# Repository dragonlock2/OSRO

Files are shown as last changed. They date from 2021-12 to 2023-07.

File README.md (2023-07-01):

# OSRO (Open-Source Reflow Oven)

OSRO is an ESP32-C3 powered WiFi-connected reflow oven controller designed for low cost and ease of use. Web UI is built on React JS for those aesthetics.

## Building

1. Build the web UI.
```
cd webui
npm install
npm run build
```
2. Follow the [instructions](https://docs.espressif.com/projects/esp-idf/en/latest/esp32/get-started/) to get ESP-IDF set up. Currently tested with ESP-IDF `v5.0.2`.
3. Setup the build for the firmware. Make sure to set the WiFi SSID and password under `OSRO WiFi configuration`.
```
cd firmware
get_idf
idf.py set-target esp32c3
idf.py menuconfig
```
4. Build and flash the firmware.
```
cd firmware
idf.py build
idf.py -p <serial port> flash
```

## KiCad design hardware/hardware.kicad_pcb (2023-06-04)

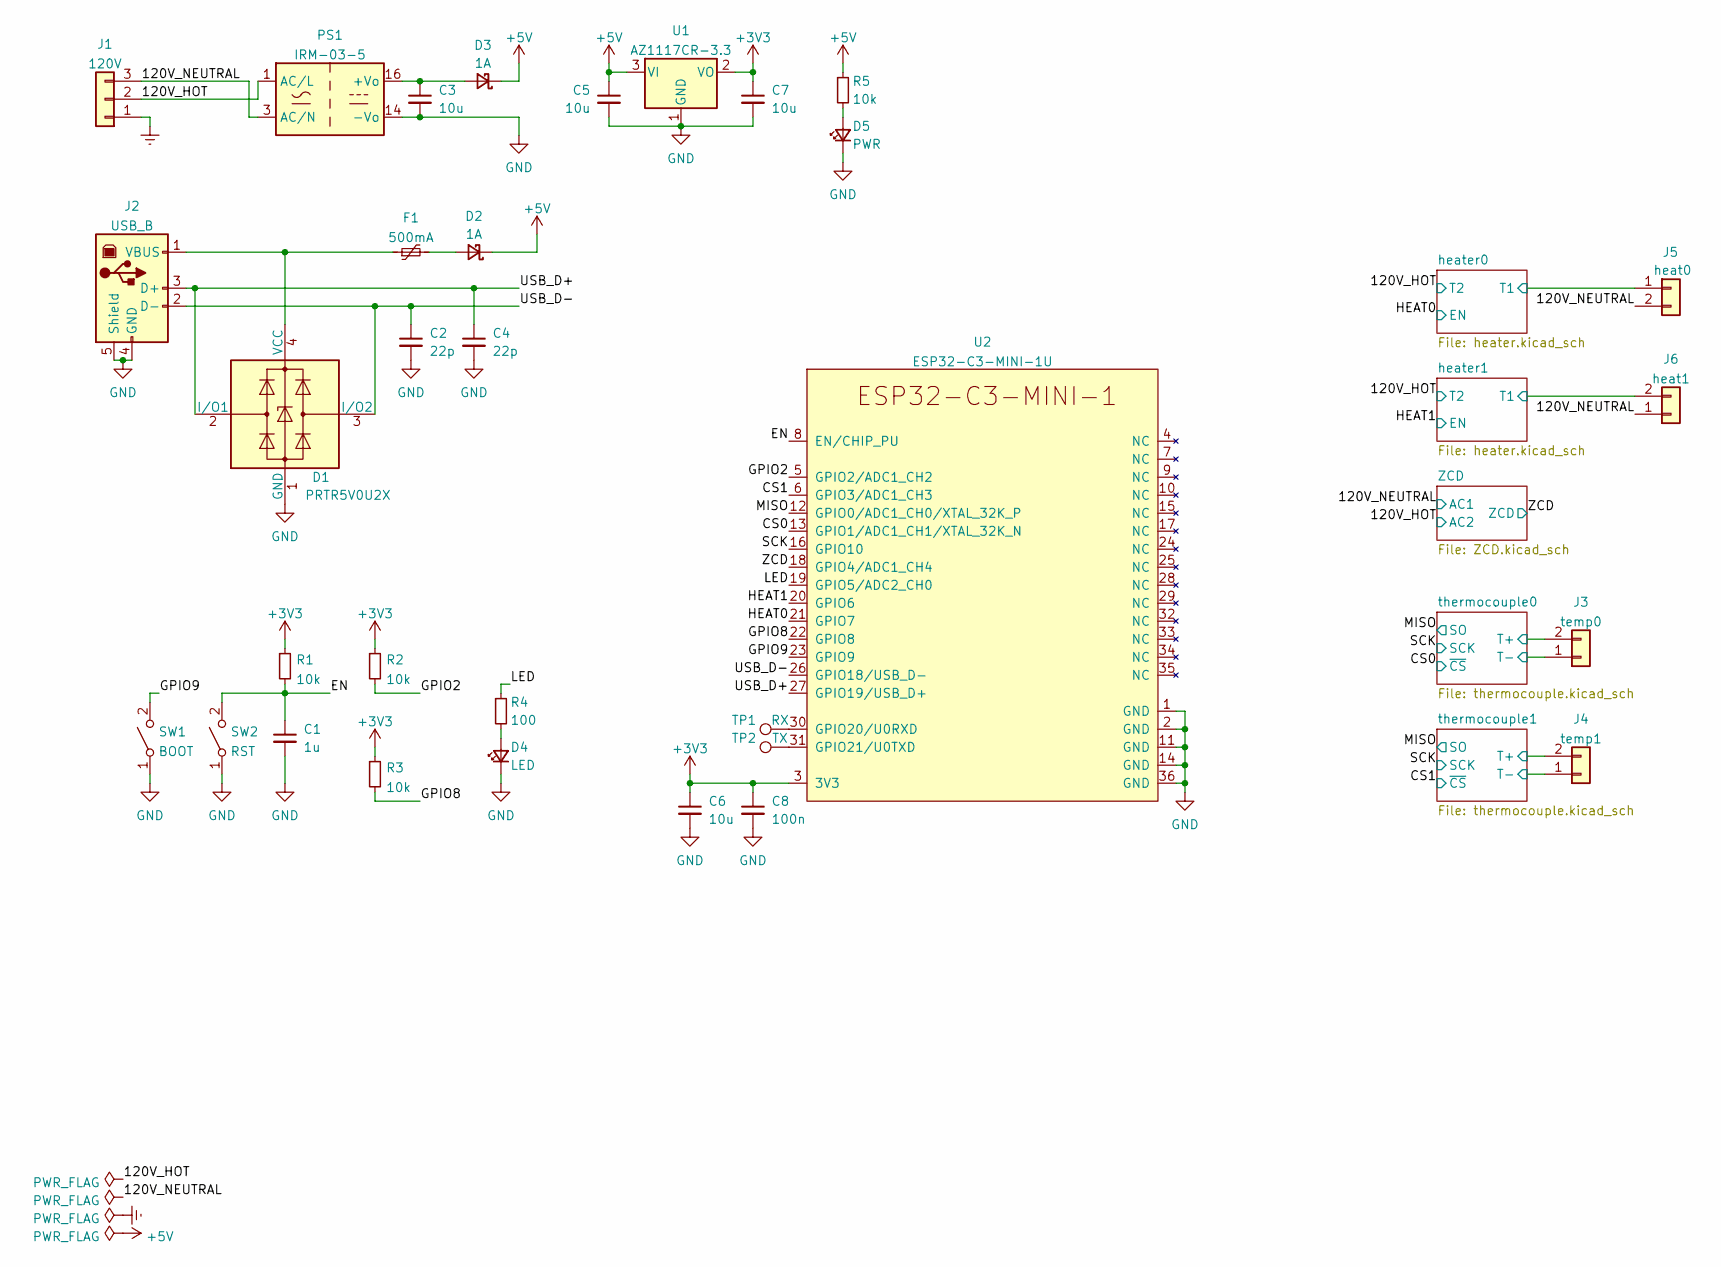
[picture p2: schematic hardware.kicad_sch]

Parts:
C1: 1u; C_0603_1608Metric
C2, C4: 22p; C_0603_1608Metric
C3, C5, C6, C7: 10u; C_0805_2012Metric
C8: 100n; C_0603_1608Metric
D1: PRTR5V0U2X; SOT-143
D2, D3: 1A; D_SOD-123F
D4: LED; LED_0603_1608Metric
D5: PWR; LED_0603_1608Metric
F1: 500mA; Fuse_1206_3216Metric
J1: 120V; Molex_MicroFit+_RH_1row_3pin
J2: USB_B; USB_B_TE_5787834_Vertical
J3: temp0; Molex_DuraClik_RH_2pin
J4: temp1; Molex_DuraClik_RH_2pin
J5: heat0; Molex_MicroFit+_RH_1row_2pin
J6: heat1; Molex_MicroFit+_RH_1row_2pin
PS1: IRM-03-5; Converter_ACDC_MeanWell_IRM-03-xx_THT
R1, R2, R3, R5: 10k; R_0603_1608Metric
R4: 100; R_0603_1608Metric
SW1: BOOT; SW_SPST_PTS810
SW2: RST; SW_SPST_PTS810
TP1: RX; TestPoint_Pad_D2.0mm
TP2: TX; TestPoint_Pad_D2.0mm
U1: AZ1117CR-3.3; SOT-89-3
U2: ESP32-C3-MINI-1U

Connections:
+3V3: C6.1, C7.1, C8.1, R1.1, R2.1, R3.1, U1.2 (VO), U2.3 (3V3); also elsewhere on the board
+5V: C5.1, D2.1 (K), D3.1 (K), R5.1, U1.3 (VI)
/120V_HOT: J1.2, PS1.1 (AC/L); also elsewhere on the board
/120V_NEUTRAL: J1.3, J5.2, J6.1, PS1.3 (AC/N); also elsewhere on the board
/CS0: U2.13 (GPIO1/ADC1_CH1/XTAL_32K_N); also elsewhere on the board
/CS1: U2.6 (GPIO3/ADC1_CH3); also elsewhere on the board
/EN: C1.1, R1.2, SW2.2 (B), U2.8 (EN/CHIP_PU)
/GPIO2: R2.2, U2.5 (GPIO2/ADC1_CH2)
/GPIO8: R3.2, U2.22 (GPIO8)
/GPIO9: SW1.2 (B), U2.23 (GPIO9)
/HEAT0: U2.21 (GPIO7); also elsewhere on the board
/HEAT1: U2.20 (GPIO6); also elsewhere on the board
/LED: R4.1, U2.19 (GPIO5/ADC2_CH0)
/MISO: U2.12 (GPIO0/ADC1_CH0/XTAL_32K_P); also elsewhere on the board
/SCK: U2.16 (GPIO10); also elsewhere on the board
/USB_D+: C4.1, D1.2 (I/O1), J2.3 (D+), U2.27 (GPIO19/USB_D+)
/USB_D-: C2.1, D1.3 (I/O2), J2.2 (D-), U2.26 (GPIO18/USB_D-)
/ZCD: U2.18 (GPIO4/ADC1_CH4); also elsewhere on the board
/heater0/T1: J5.1; also elsewhere on the board
/heater1/T1: J6.2; also elsewhere on the board
/thermocouple0/T+: J3.2; also elsewhere on the board
/thermocouple0/T-: J3.1; also elsewhere on the board
/thermocouple1/T+: J4.2; also elsewhere on the board
/thermocouple1/T-: J4.1; also elsewhere on the board
Earth: J1.1
GND: C1.2, C2.2, C3.2, C4.2, C5.2, C6.2, C7.2, C8.2, D1.1 (GND), D4.1 (K), D5.1 (K), J2.4 (GND), J2.5 (Shield), PS1.14 (-Vo), SW1.1 (A), SW2.1 (A), U1.1 (GND), U2.1 (GND), U2.2 (GND), U2.11 (GND), U2.14 (GND), U2.36 (GND); also elsewhere on the board
unnamed: C3.1, D3.2 (A), PS1.16 (+Vo)
unnamed: D1.4 (VCC), F1.1, J2.1 (VBUS)
unnamed: D2.2 (A), F1.2
unnamed: D4.2 (A), R4.2
unnamed: D5.2 (A), R5.2
unnamed: TP1.1, U2.30 (GPIO20/U0RXD)
unnamed: TP2.1, U2.31 (GPIO21/U0TXD)

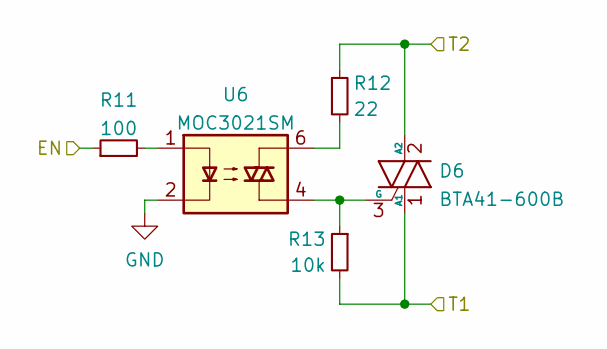
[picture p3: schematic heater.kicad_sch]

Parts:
D6: BTA41-600B; TO-3P-3_Horizontal_TabDown
R11: 100; R_0603_1608Metric
R12: 22; R_0603_1608Metric
R13: 10k; R_0603_1608Metric
U6: MOC3021SM; SMDIP-6_W9.53mm_Clearance8mm

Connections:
/120V_HOT: D6.2 (A2), R12.1; also elsewhere on the board
/HEAT0: R11.1; also elsewhere on the board
/heater0/T1: D6.1 (A1), R13.2; also elsewhere on the board
GND: U6.2; also elsewhere on the board
unnamed: D6.3 (G), R13.1, U6.4
unnamed: R11.2, U6.1
unnamed: R12.2, U6.6

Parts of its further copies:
D7: BTA41-600B; TO-3P-3_Horizontal_TabDown
R14: 100; R_0603_1608Metric
R15: 22; R_0603_1608Metric
R16: 10k; R_0603_1608Metric
U7: MOC3021SM; SMDIP-6_W9.53mm_Clearance8mm

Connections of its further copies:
/120V_HOT: D7.2 (A2), R15.1; also elsewhere on the board
/HEAT1: R14.1; also elsewhere on the board
/heater1/T1: D7.1 (A1), R16.2; also elsewhere on the board
GND: U7.2; also elsewhere on the board
unnamed: D7.3 (G), R16.1, U7.4
unnamed: R14.2, U7.1
unnamed: R15.2, U7.6

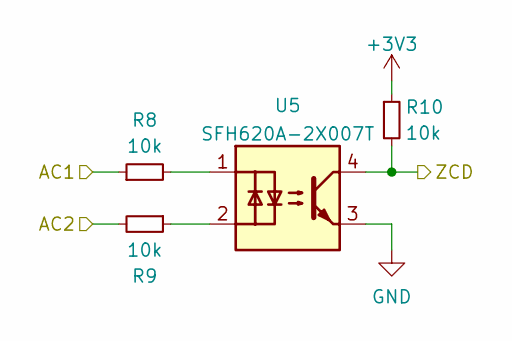
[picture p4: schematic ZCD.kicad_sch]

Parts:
R8, R9: 10k; R_1206_3216Metric
R10: 10k; R_0603_1608Metric
U5: SFH620A-2X007T; SMDIP-4_W9.53mm_Clearance8mm

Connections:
+3V3: R10.1; also elsewhere on the board
/120V_HOT: R9.2; also elsewhere on the board
/120V_NEUTRAL: R8.1; also elsewhere on the board
/ZCD: R10.2, U5.4; also elsewhere on the board
GND: U5.3; also elsewhere on the board
unnamed: R8.2, U5.1
unnamed: R9.1, U5.2

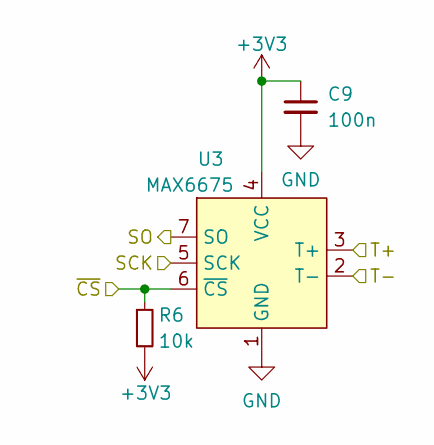
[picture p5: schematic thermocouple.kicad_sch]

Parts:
C9: 100n; C_0603_1608Metric
R6: 10k; R_0603_1608Metric
U3: MAX6675; SO-8_3.9x4.9mm_P1.27mm

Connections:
+3V3: C9.1, R6.2, U3.4 (VCC); also elsewhere on the board
/CS0: R6.1, U3.6 (~CS); also elsewhere on the board
/MISO: U3.7 (SO); also elsewhere on the board
/SCK: U3.5 (SCK); also elsewhere on the board
/thermocouple0/T+: U3.3 (T+); also elsewhere on the board
/thermocouple0/T-: U3.2 (T-); also elsewhere on the board
GND: C9.2, U3.1 (GND); also elsewhere on the board

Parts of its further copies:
C10: 100n; C_0603_1608Metric
R7: 10k; R_0603_1608Metric
U4: MAX6675; SO-8_3.9x4.9mm_P1.27mm

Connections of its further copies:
+3V3: C10.1, R7.2, U4.4 (VCC); also elsewhere on the board
/CS1: R7.1, U4.6 (~CS); also elsewhere on the board
/MISO: U4.7 (SO); also elsewhere on the board
/SCK: U4.5 (SCK); also elsewhere on the board
/thermocouple1/T+: U4.3 (T+); also elsewhere on the board
/thermocouple1/T-: U4.2 (T-); also elsewhere on the board
GND: C10.2, U4.1 (GND); also elsewhere on the board

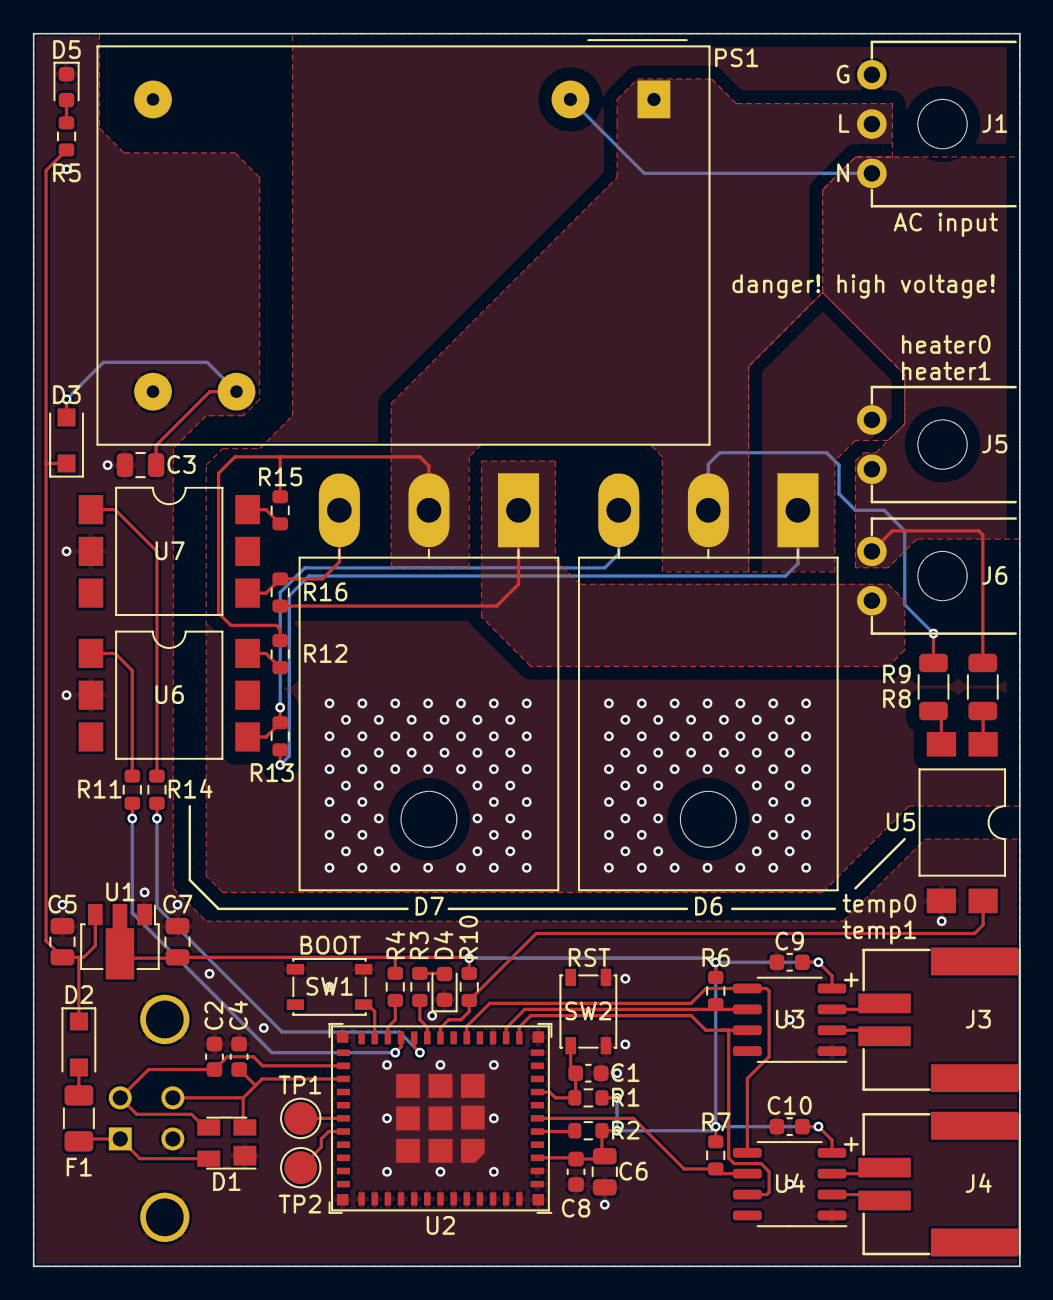
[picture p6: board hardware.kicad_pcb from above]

Board: 2 copper layers, 60.0 x 75.0 mm, 52 parts (1 on the bottom side), 40 nets.

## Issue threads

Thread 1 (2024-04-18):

230V ready?

nikwest, 2024-04-18:
Love the design. From what I can tell it should also work with 230V AC?

dragonlock2, 2024-04-18:
I haven't taken a look at this design in a while, but on a quick analysis it should work. Worst case some of the resistors in the switching circuit need to be resized.

nikwest, 2024-04-19:
ok, thank you. I'll give it a try and let you know, if it works. Any particular resistor you have in mind? I was looking at R12, but as far as I understood it, this is suppose to limit the current and the value is depending on the voltage drop of the triac. So here the AC voltage doesn't really matter.

nikwest, 2024-04-19:
Good point. Didn't think about that.

nikwest, 2024-04-21:
I can't really get resistors with correct ratings. Especially the 10k R13 and R16 I can't get with 400V rating.  I'll need to split it up into 2 5k 200V 803 resistors. Also I think it's better to use 33k for R8/R9 and SFH6206-3 instead of SFH620A-2, which has a slightly better CTR rating.
Therefore I have to touch the PCB layout. The extraparts and esspressif footprint folders are empty in the repository. I guess you haven't committed them due to copyright restrictions?

dragonlock2, 2024-04-21:
Good point on the resistor voltage rating, high voltage ones are harder to find. SFH6206-3 should be fine, parts I choose are what was cheapest on DigiKey at the time or what I had on hand so there's room for optimization.

`extraparts` and `espressif` are submodules, either do a `git clone --recursive` when cloning or a `git submodule init && git submodule update` after cloning to check those out.

nikwest, 2024-06-08:
I made a couple of changes to your design and adapted it for 230V. The first build looks like it works nicely, except that my oven is not strong enough and can't follow the profile temperature so quickly.
Question is, if you want a PR for this to incorporate in your repository or rather keep this version separate?
I also changed from USB-B to a USB-C connector and for my second board I like to use the MAX31855 instead of MAX6675. They are pin compatible, but firmware needs to be adapted.
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

dragonlock2, 2024-06-22:
That looks great! Glad that it's working. I'm a bit lazy to figure the best way to organize two board variants so let's keep your changes in a fork for now. If there's more community interest I'll take a closer look

nikwest, 2024-07-01:
Yes, I agree, just wanted to check back with you. Then I'll keep the fork.

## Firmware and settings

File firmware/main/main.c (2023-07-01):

#include <freertos/FreeRTOS.h>
#include <esp_console.h>
#include <esp_event.h>
#include <esp_log.h>
#include <nvs_flash.h>
#include "wifi.h"
#include "server.h"
#include "oven.h"

static const char *TAG = "main";

void app_main(void) {
    // console init
    esp_console_repl_t *repl = NULL;
    esp_console_repl_config_t repl_config = ESP_CONSOLE_REPL_CONFIG_DEFAULT();
    esp_console_dev_usb_serial_jtag_config_t usbjtag_config = ESP_CONSOLE_DEV_USB_SERIAL_JTAG_CONFIG_DEFAULT();
    esp_console_new_repl_usb_serial_jtag(&usbjtag_config, &repl_config, &repl);
    esp_console_start_repl(repl);

    // other init
    nvs_flash_init();
    esp_event_loop_create_default();
    
    // app init
    oven_init();
    wifi_init();
    server_init();
    ESP_LOGI(TAG, "booted!");
}

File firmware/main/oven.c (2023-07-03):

#include <math.h>
#include <stddef.h>
#include <argtable3/argtable3.h>
#include <freertos/FreeRTOS.h>
#include <freertos/semphr.h>
#include <freertos/task.h>
#include <driver/gpio.h>
#include <driver/spi_master.h>
#include <esp_console.h>
#include <esp_log.h>
#include "oven.h"

/* private data */
#define COUNT_OF(x) (sizeof(x) / sizeof(x[0]))
#define LIMIT(x, low, high) ((x < low) ? (low) : ((x > high) ? (high) : (x)))

static const int MISO_PIN  = 0;
static const int SCK_PIN   = 10;
static const int CS_PINS[] = {3}; // {1, 3};

static const int ZCD_PIN     = 4;
static const int HEAT_PINS[] = {6, 7};

#define PWM_PERIOD (30) // ~0.25s @ 60Hz AC

#define CONTROL_PERIOD (0.25) // s

static const char *TAG = "oven";

static struct {
    SemaphoreHandle_t lock;
    TickType_t        start;
    profile_type_t    type;
    oven_status_t     status;

    struct {
        struct arg_str *kp;
        struct arg_str *ki;
        struct arg_str *kd;
        struct arg_end *end;
    } pid_set_args;
    double kp, ki, kd;
    double int_err, prev_err;

    spi_device_handle_t temps[COUNT_OF(CS_PINS)];

    int pwm_counter;
    int pwm_compare;
    int pwm_compare_next;
} oven_data;

/* private helpers */
static void temp_init(void) {
    const spi_bus_config_t bus_cfg = {
        .mosi_io_num     = -1,
        .miso_io_num     = MISO_PIN,
        .sclk_io_num     = SCK_PIN,
        .max_transfer_sz = 32,
        .flags           = SPICOMMON_BUSFLAG_MASTER,
    };
    spi_bus_initialize(SPI2_HOST, &bus_cfg, SPI_DMA_DISABLED);

    for (int i = 0; i < COUNT_OF(CS_PINS); i++) {
        const spi_device_interface_config_t dev_cfg = {
            .mode           = 1,
            .clock_speed_hz = 4000000, // 4.3 MHz max
            .spics_io_num   = CS_PINS[i],
            .flags          = 0,
            .queue_size     = 1,
        };
        spi_bus_add_device(SPI2_HOST, &dev_cfg, &oven_data.temps[i]);
    }
}

static double temp_get(void) {
    // MAX6675 device
    uint8_t buf[2];
    spi_transaction_t tran = {
        .flags     = 0,
        .length    = sizeof(buf) * 8,
        .tx_buffer = NULL,
        .rx_buffer = buf,
    };

    double sum = 0.0;
    for (int i = 0; i < COUNT_OF(CS_PINS); i++) {
        spi_device_transmit(oven_data.temps[i], &tran);
        uint16_t raw = (buf[0] << 8) | buf[1];
        sum += (raw >> 3) * 0.25;
    }
    return sum / COUNT_OF(CS_PINS); // average all sensors for now
}

static void IRAM_ATTR pwm_handler(void* arg) {
    oven_data.pwm_counter++;
    if (oven_data.pwm_counter >= PWM_PERIOD) {
        oven_data.pwm_counter = 0;
        oven_data.pwm_compare = oven_data.pwm_compare_next;
    }

    bool on = oven_data.pwm_counter < oven_data.pwm_compare;
    for (int i = 0; i < COUNT_OF(HEAT_PINS); i++) {
        gpio_set_level(HEAT_PINS[i], on);
    }
}

static void pwm_init(void) {
    oven_data.pwm_counter      = 0;
    oven_data.pwm_compare      = 0;
    oven_data.pwm_compare_next = 0;

    gpio_reset_pin(ZCD_PIN);
    gpio_set_direction(ZCD_PIN, GPIO_MODE_INPUT);
    gpio_set_pull_mode(ZCD_PIN, GPIO_PULLUP_ONLY);
    gpio_set_intr_type(ZCD_PIN, GPIO_INTR_NEGEDGE);
    gpio_install_isr_service(0);
    gpio_isr_handler_add(ZCD_PIN, pwm_handler, NULL);

    for (int i = 0; i < COUNT_OF(HEAT_PINS); i++) {
        gpio_reset_pin(HEAT_PINS[i]);
        gpio_set_direction(HEAT_PINS[i], GPIO_MODE_INPUT_OUTPUT);
        gpio_set_drive_capability(HEAT_PINS[i], GPIO_DRIVE_CAP_3);
        gpio_set_level(HEAT_PINS[i], 0);
    }
}

static void pwm_set(double duty) {
    int c = round(LIMIT(duty, 0.0, 1.0) * PWM_PERIOD);
    taskENTER_CRITICAL(NULL);
    oven_data.pwm_compare_next = c;
    taskEXIT_CRITICAL(NULL);
}

static void oven_thread(void *arg) {
    temp_init();
    pwm_init();
    ESP_LOGI(TAG, "oven initialized!");

    TickType_t wait = xTaskGetTickCount();
    while (true) {
        double temp = temp_get();

        profile_status_t target = {
            .temp = ROOM_TEMP,
            .done = true,
        };
        xSemaphoreTake(oven_data.lock, portMAX_DELAY);
        oven_data.status.current = temp;
        if (oven_data.status.running) {
            double elapsed = (xTaskGetTickCount() - oven_data.start) / (portTICK_PERIOD_MS * 1000.0);
            target = profile_status(oven_data.type, elapsed);
            oven_data.status.target  = target.temp;
            oven_data.status.running = !target.done;
        }
        xSemaphoreGive(oven_data.lock);

        if (target.done) {
            oven_data.int_err  = 0.0;
            oven_data.prev_err = 0.0;
            pwm_set(0.0);
        } else {
            double err         = target.temp - temp;
            double delta_err   = (err -  oven_data.prev_err) / CONTROL_PERIOD;
            oven_data.int_err  = oven_data.int_err + err * CONTROL_PERIOD;
            oven_data.int_err  = LIMIT(oven_data.int_err, 0.0, 1.0 / oven_data.ki); // anti-windup, limit to 100%
            oven_data.prev_err = err;

            pwm_set(
                LIMIT(oven_data.kp * err,               -1.0, 1.0) +
                LIMIT(oven_data.ki * oven_data.int_err, -1.0, 1.0) +
                LIMIT(oven_data.kd * delta_err,         -1.0, 1.0)
            );
        }

        vTaskDelayUntil(&wait, (CONTROL_PERIOD * 1000) / portTICK_PERIOD_MS);
    }
    vTaskDelete(NULL);
}

static void pid_set(const char *kp, const char *ki, const char *kd) {
    oven_data.kp = atof(kp);
    oven_data.ki = atof(ki);
    oven_data.kd = atof(kd);
    ESP_LOGI(TAG, "PID kp: %.5f ki: %.5f kd: %.5f", oven_data.kp, oven_data.ki, oven_data.kd);
}

static int pid_set_command(int argc, char **argv) {
    if (arg_parse(argc, argv, (void**) &oven_data.pid_set_args) != 0) {
        arg_print_errors(stderr, oven_data.pid_set_args.end, argv[0]);
        return 1;
    }
    pid_set(
        oven_data.pid_set_args.kp->sval[0],
        oven_data.pid_set_args.ki->sval[0],
        oven_data.pid_set_args.kd->sval[0]
    );
    return 0;
}

/* public functions */
void oven_init(void) {
    oven_data.pid_set_args.kp  = arg_str1(NULL, NULL, "<kp>", "kp");
    oven_data.pid_set_args.ki  = arg_str1(NULL, NULL, "<ki>", "ki");
    oven_data.pid_set_args.kd  = arg_str1(NULL, NULL, "<kd>", "kd");
    oven_data.pid_set_args.end = arg_end(10);
    const esp_console_cmd_t pid_set_cmd = {
        .command  = "pid",
        .help     = "set PID constants",
        .hint     = NULL,
        .func     = pid_set_command,
        .argtable = &oven_data.pid_set_args,
    };
    esp_console_cmd_register(&pid_set_cmd);

    pid_set(CONFIG_PID_KP, CONFIG_PID_KI, CONFIG_PID_KD); // TODO autotune

    oven_data.lock           = xSemaphoreCreateBinary();
    oven_data.type           = PROFILE_TYPE_MANUAL;
    oven_data.status.current = ROOM_TEMP;
    oven_data.status.target  = ROOM_TEMP;
    oven_data.status.running = false;
    xSemaphoreGive(oven_data.lock);
    xTaskCreate(oven_thread, "oven", 2048, NULL, configMAX_PRIORITIES - 1, NULL);
}
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

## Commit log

2021-12-10 switched to React JS
2021-12-10 upload webui to spiffs
    [partitions.csv]
2021-12-31 add empty board files
    [hardware.kicad_pcb, hardware.kicad_sch]
2021-12-31 added esp32c3 and power
    [120V_5V_ACDC.kicad_sch, hardware.kicad_sch]
2022-01-01 add thermocouple and zcd
    [ZCD.kicad_sch, hardware.kicad_sch, thermocouple.kicad_sch]
2022-01-01 added heater
    [ZCD.kicad_sch, hardware.kicad_sch, heater.kicad_sch]
2022-01-01 assigned footprints
    [120V_5V_ACDC.kicad_sch, ZCD.kicad_sch, hardware.kicad_pcb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]
2022-01-01 layout WIP
    [hardware.kicad_pcb, hardware.kicad_sch, heater.kicad_sch]
2022-01-02 finished layout
    [ZCD.kicad_sch, hardware.kicad_pcb, hardware.kicad_sch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]
2022-01-28 basic testing except heater done
    [hardware.kicad_sch, heater.kicad_sch, thermocouple.kicad_sch]
2022-02-08 added bang-bang implementation
    [hardware.kicad_pcb, heater.kicad_sch]
2023-06-04 update to KiCad 7
    [ZCD.kicad_sch, hardware.kicad_pcb, hardware.kicad_sch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]
2023-06-14 WIP refactor wifi driver
    [partitions.csv]
2023-07-01 add PID support
2023-07-03 update ui/pid a bit
